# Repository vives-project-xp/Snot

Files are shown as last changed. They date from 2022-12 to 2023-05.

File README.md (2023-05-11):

# SNOT

Safe Night Out Together is een project waar er wordt geprobeerd om spiking zo veel mogelijk tegen te houden. Wij hebben een dop ontwikkeld die dir probeerd tegen te houden. De bedoeling is dat je een nfc bandje scant op de dop en dat deze dan open zal gaan, als deze eraf wordt geforceerd zal er een lichtje branden, die de persoon inlicht om het drankje weg te gieten.

## Discord

Join het discord kanaal voor alle info en vragen: [Discord](https://discord.gg/33ayYHaHzA))

Bekijk ook onze [promovideo!](https://www.youtube.com/watch?v=ft7jXlZkHr0&feature=youtu.be)

Zie ook:  [Redmine](https://project.devbit.be/projects/snot)

## Dop Design

Voorlopig hebben we een aantal designs gehad. Het laatste design is de blauwe dop.
Zie discord INFO/Design voor verdere info.

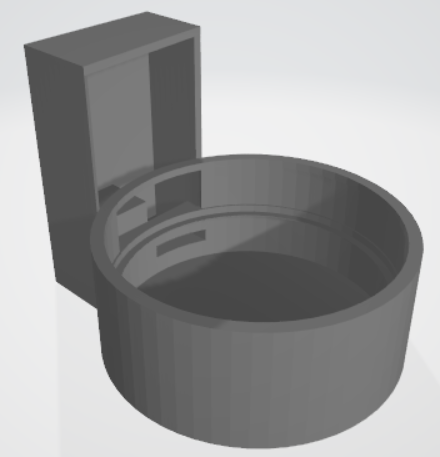
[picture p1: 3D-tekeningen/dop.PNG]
foto dop


Dit is een foto van de dop, in het grote gat komt een servo motor, die het glas klem zet. Er zit ook nog een dubbele bodem in voor de pcb, maar die hebben we niet kunnen uittesten.

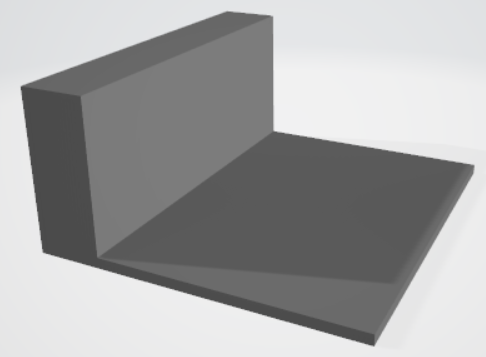
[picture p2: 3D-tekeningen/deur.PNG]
foto deur


Dit is een foto van het deurtje dat de servo motor zal in plaats houden en beschermen.

## PCB Design

Om de shield te laten werken moet je hem in SPI mode zetten. Voor SPI moet je SEL0 en SEL1 sluiten, je moet ze dus dichtsolderen of met een schakelaar connecteren.

Om de shield te verbinden met bv. een nucleo moet je 3 power pinnen(5V, 3V3 en GND) en 4 spi pinnen(MOSI, MISO, SCK, en CS/SS) verbinden.

In het mapje bcp staat er een mapje snot_pcb. Hierin staat de kicad file voor de pcb, deze kan gebruikt worden om de pcb online te bestellen. Er staat ook een BOM lijst met de benodigde materialen. 

## Benodigdheden Software

- Installeren van Visual Studio Code: <https://code.visualstudio.com/> // + Benodigde extenties (zou moeten automatisch aanbieden welke je nodig hebt)
- Installeren van python: <https://www.academicsoftware.eu/software/27/265> // Take the lastest STABLE release
- Installeren van (mini)conda: <https://software-installation-guide.netlify.app/conda/>
- Installeren van mbed: <https://software-installation-guide.netlify.app/mbed/>
- Installeren van KiCad: <https://www.kicad.org/download/windows/> // CERN Switzerland
- Installeren van SolidEdge: <https://www.academicsoftware.eu/software/25/292>

Zorg er ook voor dat miniconda is toegevoegd aan je omgevings variabelen: bv. C:\Users\thybr\miniconda3\Scripts

## Code

Voor het binnenhalen van de code en overige:
```bash
git clone https://github.com/vives-project-xp/Snot.git
git checkout snot-v2
```

De volledige code is terug te vinden onder de file 'mbed'.
Indien je de schakeling wil testen zonder de NFC maar enkel met drukknoppen moet je de file 'cap' gebruiken

Voor het compileren van de code:

- Open powershell
- Conda create mbed (zie installation guide (mini)conda)
- Conda activate mbed (zie installation guide (mini)conda voor installatie extensies)
- Compileren van de code
```bash 
mbed compile -f
```

Er is ook code voor de box, maar die heeft zijn eigen README.md.
Deze code was van een vorig project en wij hebben die aangepast voor ons project. Er zijn teveel files die we niet gebruiken, maar alle klasses zijn met elkaar verbonden en hierdoor is het te veel werk om de bestanden te verwijderen die we niet gebruiken. In citygame-displaydriver/Display.cpp is most of the code.

## Opstelling Cap 

[Hier](https://www.instagram.com/reel/CrSmLBvvxVR/?utm_source=ig_web_copy_link) is een demo van de opstelling.

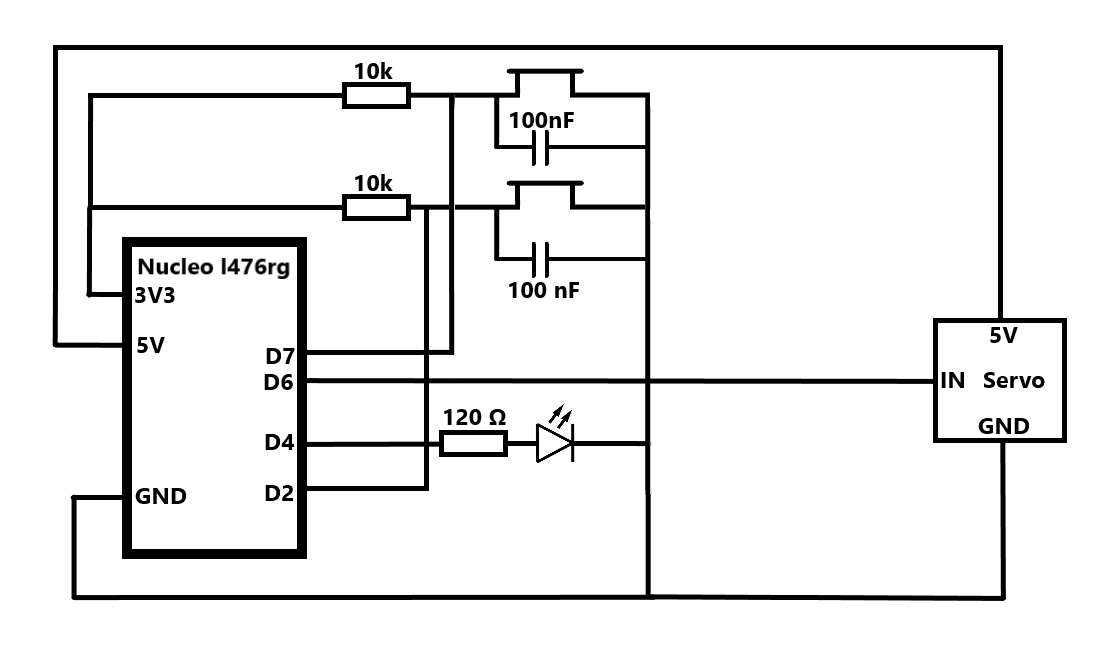
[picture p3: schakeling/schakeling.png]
schakeling

Dit is de schakeling die gebruikt wordt in de demo, deze heeft 2 knoppen. 1 knop hiervan simuleert de nfc, omdat wij deze nog niet hebben. Het filmpje legt ook uit hoe deze precies werkt.

## NFC

There is code for the NFC included, but we haven't been able to test it out. In the code for the box, there is a file called citygame-displaydriver/Display.cpp. This is where most of the code for the box is and here you will have to add your own NFC code.

## Benodigdheden Hardware

- Cap + valse bodem + dekseltje motor
- STM32L467RG voor compilatie
- PN532 (versie blauw) voor scannen van de NFC --> soort versie kan nog veranderen ondertussen
- Zelfgemaakte PCB wanneer werken voor STM te vervangen (zou moeten in cap passen)
- PN532 (versie rood) voor het scannen van de NFC (zou moeten in de cap passen)
- Alle bestelde hardware + deze solderen op de zelf gemaakte PCB (zie mapje pcb)

## TODO

- De pcb solderen en dan NFC daarin implementeren
- NFC code voor de box maken

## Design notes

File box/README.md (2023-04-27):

# VivesCityGame:

## What does this do?

This is the firmware for the K64F mbed board that runs the VivesCityGame hardware box.

More info here > https://citygame.labict.be/

## How to install libraries and compile?

```bash
git clone https://github.com/vives-project-xp/Snot.git
git checkout snot-v2
cd .\box
conda activate mbed
mbed deploy
mbed compile -f
```

## License

Distributed under the [MIT](https://opensource.org/licenses/MIT) license.

## Notes

Make sure to replace Debug.h the SX1276Lib with this one:
https://developer.mbed.org/users/ghysbrecht/code/SX1276Lib/

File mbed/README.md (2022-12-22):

# Here can u find code for MBED NFC reader

## Installation

1. Import project
2. cd ./Snot/mbed
3. mbed deploy
4. Connect NUCLEO_L476RG
5. > mbed compile -t GCC_ARM --flash
(You can also use make)
6. Everything is done!

## Working

The board communicates with the PN532 through the SPI protocol. On startup it enters a discovery mode in which it searches a NFC signal to pair itself to. After it's paired the cap only unlocks with the paired NFC tag. This process can be reset by presenting the master-tag configured for the system. The master tag opens the cap and puts it into the discovery mode.

## Version

Project was tested on:
compiler: 10.3.1

> mbed ls
  mbed ( revision in the current branch)
  `- mbed-os (#54e8693ef4ff, tags: mbed-os-6.16.0, mbed-os-6.16.0-rc1)

## How does the code work?

### Helper Object

Helper class contains most of the functions used in the Main loop just to keep
main.cpp cleaner and make things easier to find.

### Led Object

Contains led controls methods.

### pn532 Library

Library that contains all the RFID methods and communication between
Nucleo and pn532.

### Main Loop

Check comments <3

## Mifare classic 1k

[Download link to PDF for Mifare datasheet](https://www.google.com/url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)

On page 3 you can see memory map for this card.
As u can see this card has 16 sectors with 4 blocks in each sector.

In first sector is manufacturer data that is read-only

In first 3 blocks of each sector u can put any data u want within 2bytes.
The 4th block is serverd for keyA, Access Bits and keyB.

KeyA and KeyB are sort of "passwords" for the entire sector.
ex. If you would change KeyA in block 7, you'll have to authenticate
blocks from 4-7 with the new key.

Access bits change how they keys are read so if u don't know what you're doing
best keep these the way they or you can lock your self out of the sector.

The way we work with the card is we first use the helper.set... method to set each card with
default values for everyone of them.

By first changing every cards keyA to sector2 to other than manufacturers default key
and put password in the 8th block.

## Light Signals

Fast blinking green light = saving new card
Green light = good card

Flashing red light = bad card

Flashing green and red light = master card

Constant flashing red light = Opened cap without NFC card
To reset close cap and present master card

Constant blue light = pn532 board not found

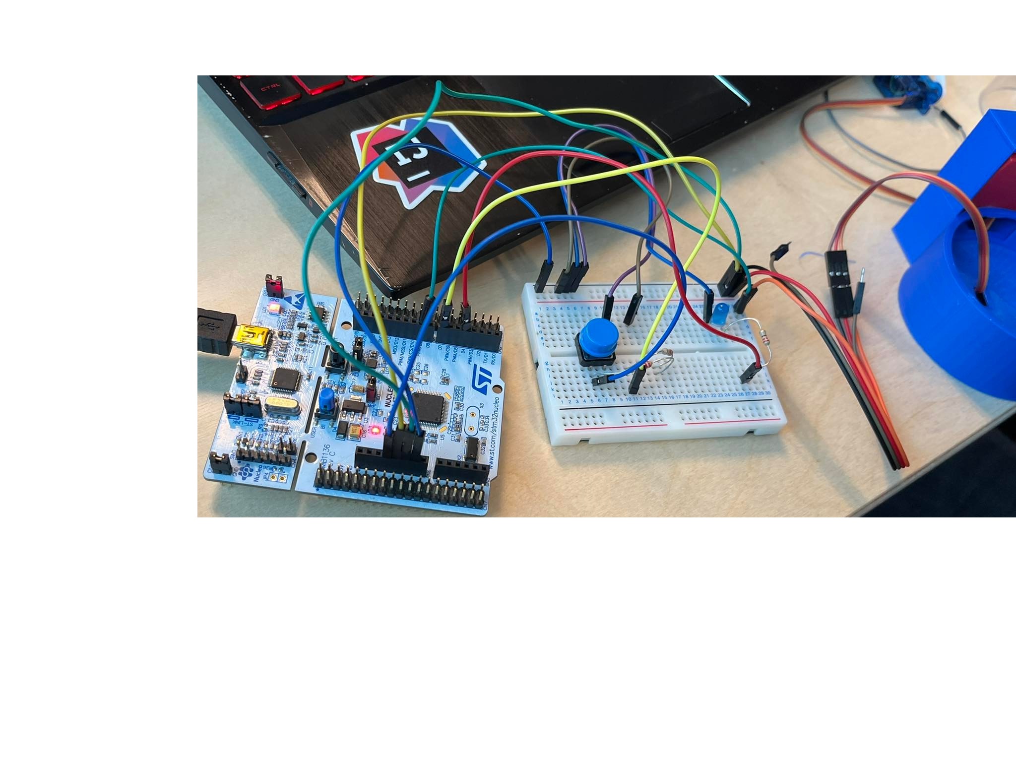
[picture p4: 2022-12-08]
fotos/opstellingCap.jpg

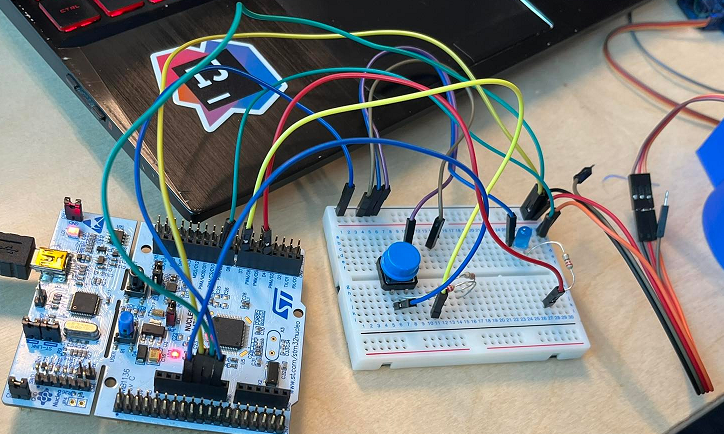
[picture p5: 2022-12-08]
fotos/opstellingCap.png

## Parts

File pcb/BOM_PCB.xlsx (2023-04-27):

Aantal | Korte omschrijving | Winkel | Artikelnummer | URL | Totale kostprijs | NFC gedeelte
2 | RFID/NFC Reader | Otronic | OT2053-D82 | https://www.otronic.nl/nl/pn532-rfid-nfc-kit-met-s50-kaart-en-s50-key-tag.html | 19.98 | x
10 | Batterijhouder | Farnell | 1650693 | https://nl.farnell.com/keystone/3002/battery-smd-retainer-20mm/dp/1650693 | 9.22
10 | Drukknop | Farnell | 1333652 | https://nl.farnell.com/omron/b3u-1000p/switch-spst-no-0-05a-12v-smd/dp/1333652 | 9.38
60 | 100nF condensator | Farnell | 1327679 | https://be.farnell.com/avx/0603yc104kat2a/cap-0-1-f-16v-10-x7r-0603/dp/1327679?st=0603%20100nf | 1.92
20 | 220ohm weerstand | Farnell | 2670071 | https://be.farnell.com/walsin/wf08p2200ftl/res-220r-1-0-25w-0805-thick-film/dp/2670071?ICID=I-RP-STM7REC-2 | 0.12
10 | Microcontrollers | Farnell | 3011633 | https://be.farnell.com/stmicroelectronics/stm32l412k8u6/mcu-32bit-80mhz/dp/3011633 | 50.04
50 | Pin Headers | Farnell | 1539412 | https://be.farnell.com/multicomp/2211s-03g/header-1-row-vert-3way/dp/1593412?st=angled%202.54mm%20pin%20header | 0.98
20 | 82ohm weerstand | Farnell | 2447730 | https://be.farnell.com/multicomp/mcwr08x82r0ftl/res-82r-1-0-125w-thick-film/dp/2447730?st=82ohm%20smd%200805 | 0.16
20 | 150ohm weerstand | Farnell | 3994492 | https://be.farnell.com/walsin/mr08x151-jtlv/res-150r-5-0-25w-0805-thick-film/dp/3994492?st=150ohm%20smd%200805 | 0.08
1 | 10 knoopcelbatterijen | bol.com | x | https://www.bol.com/be/nl/p/varta-cr2032-knoopcel-batterij-10-stuks/9200000052955519/?s2a= | 10.7
4 | RFID/NFC kaarten | Kiwi | KW-1706 | https://www.kiwi-electronics.com/nl/13-56mhz-rfid-nfc-kaart-1kb-863?search=nfc | 11.8 | x
4 | RFID/NFC Tags | Kiwi | KW-2134 | https://www.kiwi-electronics.com/nl/13-56mhz-rfid-nfc-sleutelhanger-3711?search=nfc | 3.8 | x

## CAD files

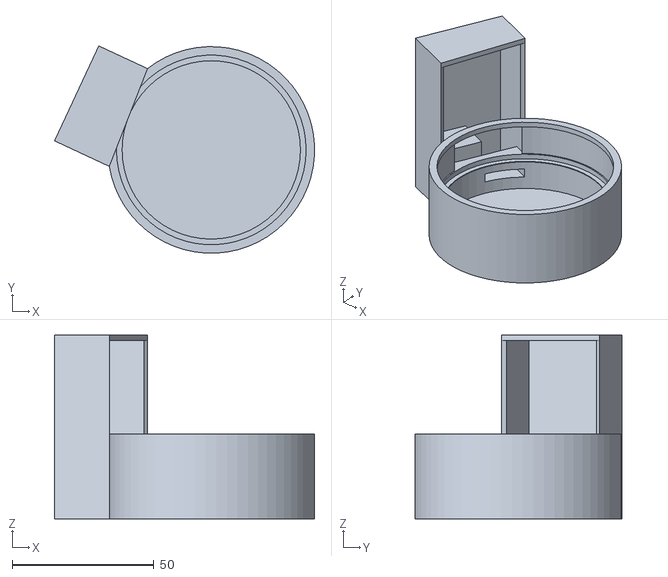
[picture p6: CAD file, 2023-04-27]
3D-tekeningen/cap_open_motor5.stl
91.9 x 73.2 x 65.0

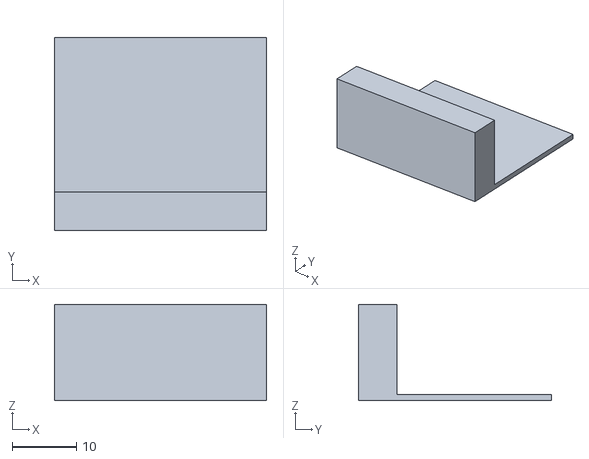
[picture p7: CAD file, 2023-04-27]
3D-tekeningen/motor_door2.stl
33.0 x 30.0 x 15.0

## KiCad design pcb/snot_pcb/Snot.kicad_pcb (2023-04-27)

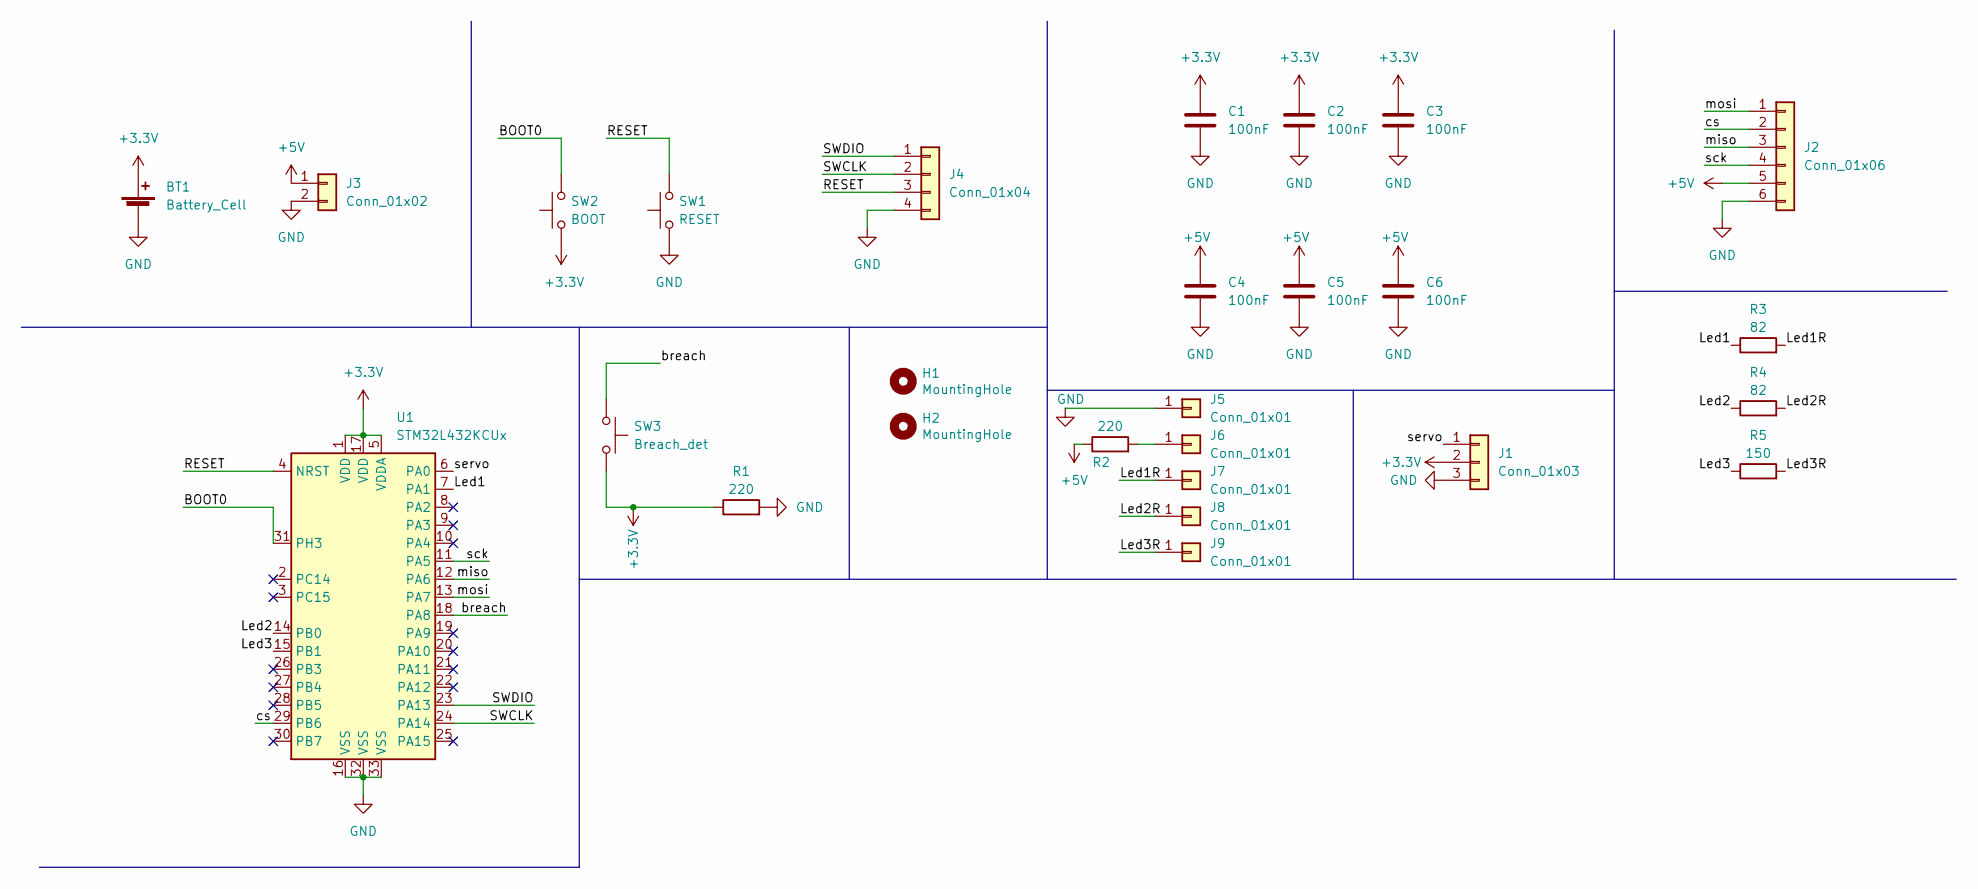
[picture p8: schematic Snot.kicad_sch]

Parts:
BT1: Battery_Cell; BatteryHolder_Keystone_3002_1x2032
C1, C2, C3, C4, C5, C6: 100nF; C_0603_1608Metric_Pad1.08x0.95mm_HandSolder
H1, H2: MountingHole; MountingHole_3.2mm_M3
J1: Conn_01x03; PinHeader_1x03_P2.54mm_Vertical
J2: Conn_01x06; PinHeader_1x06_P2.54mm_Vertical
J3: Conn_01x02; PinHeader_1x02_P2.54mm_Vertical
J4: Conn_01x04; PinHeader_1x04_P2.54mm_Vertical
J5, J6, J7, J8, J9: Conn_01x01; SolderWirePad_1x01_SMD_1x2mm
R1, R2: 220; R_0805_2012Metric_Pad1.20x1.40mm_HandSolder
R3, R4: 82; R_0805_2012Metric_Pad1.20x1.40mm_HandSolder
R5: 150; R_0805_2012Metric_Pad1.20x1.40mm_HandSolder
SW1: RESET; SolderJumper-2_P1.3mm_Open_Pad1.0x1.5mm
SW2: BOOT; SolderJumper-2_P1.3mm_Open_Pad1.0x1.5mm
SW3: Breach_det; SW_SPST_B3U-1000P
U1: STM32L432KCUx; QFN-32-1EP_5x5mm_P0.5mm_EP3.45x3.45mm

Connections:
+3V3: BT1.1 (+), C1.1, C2.1, C3.1, J1.2, R1.1, SW2.1, SW3.2, U1.1 (VDD), U1.5 (VDDA), U1.17 (VDD)
+5V: C4.1, C5.1, C6.1, J2.5, J3.1, R2.1
/BOOT0: SW2.2, U1.31 (PH3)
/Led1: R3.1, U1.7 (PA1)
/Led1R: J7.1, R3.2
/Led2: R4.1, U1.14 (PB0)
/Led2R: J8.1, R4.2
/Led3: R5.1, U1.15 (PB1)
/Led3R: J9.1, R5.2
/RESET: J4.3, SW1.2, U1.4 (NRST)
/SWCLK: J4.2, U1.24 (PA14)
/SWDIO: J4.1, U1.23 (PA13)
/breach: SW3.1, U1.18 (PA8)
/cs: J2.2, U1.29 (PB6)
/miso: J2.3, U1.12 (PA6)
/mosi: J2.1, U1.13 (PA7)
/sck: J2.4, U1.11 (PA5)
/servo: J1.1, U1.6 (PA0)
GND: BT1.2 (-), C1.2, C2.2, C3.2, C4.2, C5.2, C6.2, J1.3, J2.6, J3.2, J4.4, J5.1, R1.2, SW1.1, U1.16 (VSS), U1.32 (VSS), U1.33 (VSS)
unnamed: J6.1, R2.2

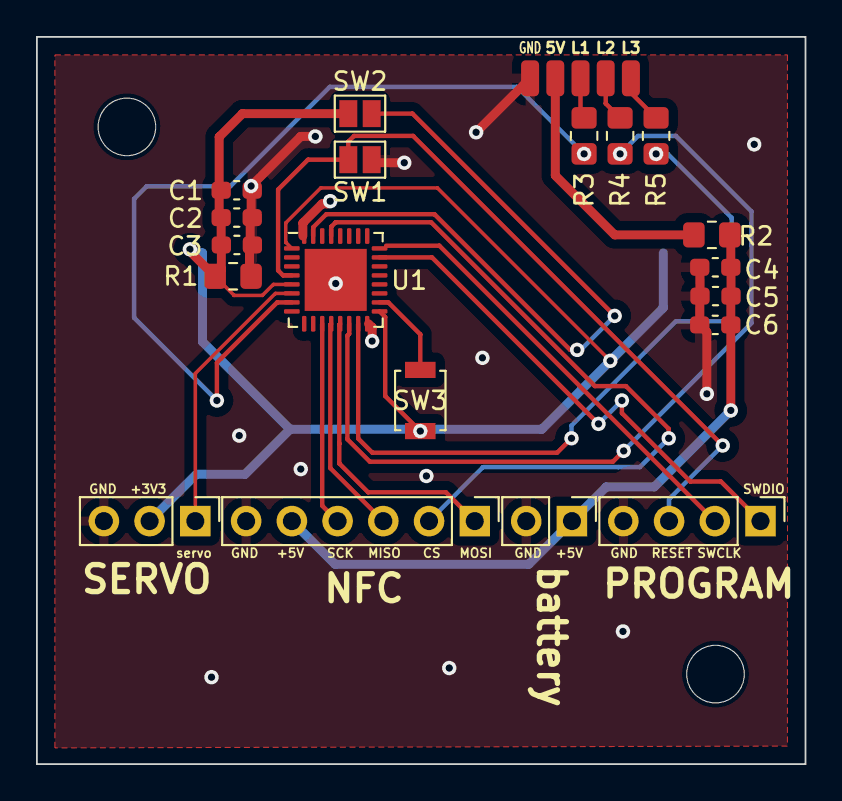
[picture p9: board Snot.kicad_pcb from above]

Board: 2 copper layers, 42.7 x 40.4 mm, 27 parts (1 on the bottom side), 20 nets.

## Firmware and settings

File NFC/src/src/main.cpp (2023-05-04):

#include "PN532.h"
#include "mbed.h"

#define NOTE_A4  440
#define NOTE_G7  3136

BusOut leds(LED1, LED2, LED3, LED4);
PN532 rfid(p5, p6, p7, p8);
Timer readTimer;
PwmOut speaker(p21);

void loop();

int main() {
    printf("Hello!\r\n");

    uint32_t versiondata = rfid.getFirmwareVersion();
    if (!versiondata) {
        printf("Didn't find PN53x board\r\n");
        while (1); // halt
    }

    printf("Found chip PN5%lx\r\n", ((versiondata>>24) & 0xFF));
    printf("Firmware ver. %lu.%lu\r\n", (versiondata>>16) & 0xFF,
           (versiondata>>8) & 0xFF);

    rfid.SAMConfig();

    printf("Waiting for an ISO14443A Card ...\r\n");

    while (1) {
        loop();
    }
}

void beep(uint16_t note, uint16_t duration) {
    speaker.period(1.0/float(note));
    speaker = 0.25;
    wait_ms(duration);
    speaker = 0;
}

void loop() {
    uint8_t success, i;
    uint8_t uid[] = { 0, 0, 0, 0, 0, 0, 0 };  // Buffer to store the returned UID
    uint8_t uidLength;                        // Length of the UID (4 or 7 bytes depending on ISO14443A card type)
    static uint8_t lastUID[7];
    static uint8_t lastUIDLength;
    uint8_t newCardFound;

    // Wait for an ISO14443A type cards (Mifare, etc.).  When one is found
    // 'uid' will be populated with the UID, and uidLength will indicate
    // if the uid is 4 bytes (Mifare Classic) or 7 bytes (Mifare Ultralight)
    success = rfid.readPassiveTargetID(PN532_MIFARE_ISO14443A, uid, &uidLength);

    // Compare and see if we are seeing a new card
    newCardFound = 0;
    if (success) {
        if (readTimer.read_ms() > 400) {
            newCardFound = 1;
        }
        readTimer.reset();

        if (uidLength != lastUIDLength) {
            newCardFound = 1;
        } else {
            for (i = 0; i < uidLength; i++) {
                if (uid[i] != lastUID[i]) {
                    newCardFound = 1;
                    break;
                }
            }
        }
    }

    if (newCardFound) {
        for (i = 0; i < uidLength; i++) {
            lastUID[i] = uid[i];
        }
        lastUIDLength = uidLength;

        leds = 0xF;

        if (uidLength == 4) {
            // We probably have a Mifare Classic card ...
            uint32_t cardid = uid[0];
            cardid <<= 8;
            cardid |= uid[1];
            cardid <<= 8;
            cardid |= uid[2];
            cardid <<= 8;
            cardid |= uid[3];


            // Now we need to try to authenticate it for read/write access
            // Try with the factory default KeyA: 0xFF 0xFF 0xFF 0xFF 0xFF 0xFF
            uint8_t keya[6] = { 0xFF, 0xFF, 0xFF, 0xFF, 0xFF, 0xFF };

            // Start with block 4 (the first block of sector 1) since sector 0
            // contains the manufacturer data and it's probably better just
            // to leave it alone unless you know what you're doing
            success = rfid.mifareclassic_AuthenticateBlock(uid, uidLength, 4, 0, keya);

            if (success) {
                uint8_t data[16];

                // If you want to write something to block 4 to test with, uncomment
                // the following line and this text should be read back in a minute
                // memcpy(data, (const uint8_t[]){ 0, 0, 0, 0, 0, 0, 0, 0, 0, 0xE, 0xC, 0xE, 4, 1, 8, 0 }, sizeof data);
                // success = rfid.mifareclassic_WriteDataBlock (4, data);

                // Try to read the contents of block 4
                success = rfid.mifareclassic_ReadDataBlock(4, data);

                // printf("Seems to be a Mifare Classic card #%lu\r\n", cardid);
                if (success) {
                    // Data seems to have been read ... spit it out
                    leds = 0x6;
                    beep(NOTE_G7, 200);

                    // Display some basic information about the card
                    printf("Found an ISO14443A card\r\n");
                    printf("  UID Length: %d bytes\r\n", uidLength);
                    printf("  UID Value: ");
                    rfid.PrintHex(uid, uidLength);

                    printf("Seems to be a Mifare Classic card #%lu\r\n", cardid);

                    printf("Reading Block 4: ");
                    rfid.PrintHexChar(data, 16);
                    printf("\r\n");
                } else {
                    leds = 0x9;
                    beep(NOTE_A4, 800);

                    printf("Found an ISO14443A card\r\n");
                    printf("  UID Length: %d bytes\r\n", uidLength);
                    printf("  UID Value: ");
                    rfid.PrintHex(uid, uidLength);

                    printf("Seems to be a Mifare Classic card #%lu\r\n", cardid);
                    printf("Ooops ... unable to read the requested block.  Try another key?\r\n");
                    printf("\r\n");
                }
            } else {
                leds = 0x9;
                beep(NOTE_A4, 800);

                printf("Found an ISO14443A card\r\n");
                printf("  UID Length: %d bytes\r\n", uidLength);
                printf("  UID Value: ");
                rfid.PrintHex(uid, uidLength);

                printf("Seems to be a Mifare Classic card #%lu\r\n", cardid);
                printf("Ooops ... authentication failed: Try another key?\r\n");
                printf("\r\n");
            }
        } else {
            leds = 0x9;
            beep(NOTE_A4, 800);

            printf("Found an ISO14443A card\r\n");
            printf("  UID Length: %d bytes\r\n", uidLength);
            printf("  UID Value: ");
            rfid.PrintHex(uid, uidLength);

            printf("Unsupported card type\r\n");
            printf("\r\n");
        }

        wait_ms(200);
        leds = 0;

        readTimer.reset();
        readTimer.start();
    }
}



//void setup(void)
//{
//	nfc.begin();
	//...
//}

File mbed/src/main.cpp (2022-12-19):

#include "mbed.h"
#include "pn532.h"
#include "Servo.h"
#include "helpers.h"
#include "Led.h"

//add thread for led blinking
PN532 m_rfid(D11, D12, D13, D10);
Servo m_cap(D9);

// change it to be inside Led object
PwmOut red(PA_1); 
PwmOut green(PB_0);
PwmOut blue(D6);  // should be PB_3

Helpers::Led led(&red, &green, &blue);
Helpers::Helper helper(&m_rfid, &m_cap, &led);

bool firstCard = true;
void loop();

uint8_t password[6] = { 0 };

int main() {
    printf("Hello!\r\n");
        // Checks if it can detect the PN532 shield
        // if not found check if you use SPI or I2C
        // and your wires
        uint32_t versiondata = m_rfid.getFirmwareVersion();
        if (!versiondata) {
            printf("Didn't find PN53x board\r\n");
            helper.led->blue();
            while(1);
        }

    printf("Found chip PN5%lx\r\n", ((versiondata>>24) & 0xFF));
    printf("Firmware ver. %lu.%lu\r\n", (versiondata>>16) & 0xFF, (versiondata>>8) & 0xFF);

    m_rfid.SAMConfig();

    printf("Waiting for an ISO14443A Card ...\r\n");

    while (true) {
        loop();
    }
}

// Main loop
void loop() {
    bool success;
    uint8_t uid[] = { 0, 0, 0, 0, 0, 0, 0 };  // Buffer to store the returned UID
    uint8_t uidLength;                        // Length of the UID (4 or 7 bytes depending on ISO14443A card type)
    uint8_t keyA[6] = { 0x31, 0x32, 0x33, 0x00,0x00,0x00};

    // Wait for an ISO14443A type cards (Mifare, etc.).  When one is found
    // 'uid' will be populated with the UID, and uidLength will indicate
    // if the uid is 4 bytes (Mifare Classic) or 7 bytes (Mifare Ultralight)

    // tldr; waits for card
    success = m_rfid.readPassiveTargetID(PN532_MIFARE_ISO14443A, uid, &uidLength);

    if (uidLength != 4) {helper.unsupportedCard(uid, uidLength); return;} 
    // We probably have a Mifare Classic card ...
    uint32_t cardid = uid[0];
    cardid <<= 8;
    cardid |= uid[1];
    cardid <<= 8;
    cardid |= uid[2];
    cardid <<= 8;
    cardid |= uid[3];

    // To set cards uncoment single line of your choice and return.
    // If the card is set you will see prompt in terminal
    // after this it will fail because keyA will be changed
    
    // helper.setMaster(uid, uidLength);
    // helper.setGood(uid, uidLength);
    // helper.setBad(uid, uidLength);
    // return;

    // Authenticate with default keyA set by me :)
    success = m_rfid.mifareclassic_AuthenticateBlock(uid, uidLength, 8, 0, keyA);
    if (!success) {helper.error(uid, uidLength, cardid); return;}

    uint8_t data[16];

    // Try to read password from block 4
    success = m_rfid.mifareclassic_ReadDataBlock(8, data);
    if (!success) {helper.error(uid, uidLength, cardid); return; }
    
    // Uncomment to display some basic information about the card
    // helper.defaultCardInfo(uid, uidLength, cardid);

    // check master card
    // if master card found, look for new card to save passowrd
    if(helper.checkMaster(data)) {
        firstCard = true;
        helper.openCap();
        // Show with lights that master card is found
        for(int i = 0; i < 3; i++){
            helper.led->green();
            ThisThread::sleep_for(50ms);
            helper.led->red();
            ThisThread::sleep_for(50ms);
        }
        helper.led->clear();
        return;
    }

    // if firstcard save password inside
    if(firstCard) {
        for(int i = 0; i < 6; i++){
            password[i] = data[i];
            helper.led->green();
            ThisThread::sleep_for(50ms);
            helper.led->clear();
            ThisThread::sleep_for(50ms);
            
        }
        
        printf("Saved new card\r\n");
        firstCard = false;
        ThisThread::sleep_for (200ms);
        return;
    }

    // check if password in block 4 is correct
    for(int i = 0; i < 6; i++) { // later check for crash
        if(data[i] != password[i]){
            helper.badCard();
            ThisThread::sleep_for (200ms);
            return;
        }
    }

    helper.goodCard();
}

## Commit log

2022-10-06 Added current version of presentation
2022-10-18 add code for motor and servo
2022-10-20 Added comment for error logging
    [main.cpp]
2022-11-10 prototype code cap
2022-11-10 NFC example code not working, working on mbed-os/connec/nfc/src/NFCEEPROM.CPP
    [main.cpp]
2022-11-25 restoring servoExample
2022-11-28 implemented Servo - need to test
2022-12-08 Added ledstrip Pinnames in comment
2022-12-08 Need to fix password
    [main.cpp]
2022-12-08 Added thread for blinking led
2022-12-15 Added Led class
2022-12-15 Implemented Led object
2022-12-15 Adjusted pins for led
2022-12-15 Switched to single thread for blinks
2022-12-15 Switched RGB to green method
2022-12-15 Added master led signal
2022-12-15 fix typo in directory and fix whitespaces
    [main.cpp]
2022-12-15 Added blue light when pn532 board not found
2022-12-19 test for button
2022-12-22 Changed only master can reset LED open without NFC
2023-03-14 1 button
2023-04-27 readme deels aangepast + extra bestanden
    [BOM_PCB.xlsx, Snot.kicad_pcb, Snot.kicad_sch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]
2023-04-27 readme aangepast
    [BOM_PCB.xlsx]
